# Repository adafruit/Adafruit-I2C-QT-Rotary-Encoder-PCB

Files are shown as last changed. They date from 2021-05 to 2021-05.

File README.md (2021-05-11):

## Adafruit I2C QT Rotary Encoder with NeoPixel - STEMMA QT / Qwiic PCB

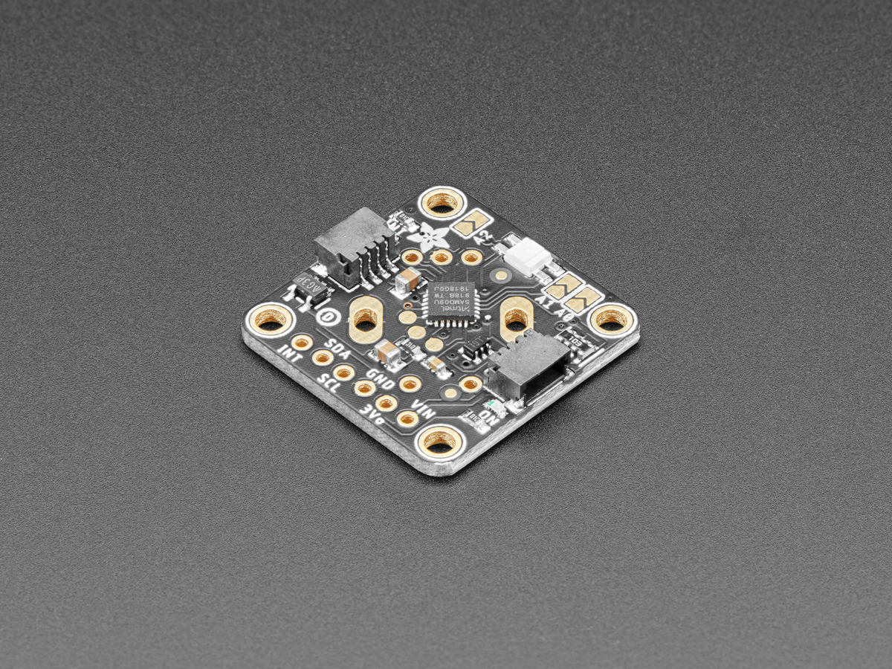
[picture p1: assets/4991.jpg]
<a href="http://www.adafruit.com/products/4991"><br/>
Click here to purchase one from the Adafruit shop</a>

PCB files for the Adafruit I2C QT Rotary Encoder with NeoPixel - STEMMA QT / Qwiic. 

Format is EagleCAD schematic and board layout
* https://www.adafruit.com/product/4991

### Description

Rotary encoders are soooo much fun! Twist em this way, then twist them that way. Unlike potentiometers, they go all the way around, and often have little detents for tactile feedback. But, if you've ever tried to add encoders to your project you know that they're a real challenge to use: timers, interrupts, debouncing...

This Stemma QT breakout makes all that frustration go away - solder in any 'standard' PEC11-pinout rotary encoder with or without a push-switch. The onboard microcontroller is programmed with our seesaw firmware and will track all pulses and pins for you and then save the incremental value for querying at any time over I2C. Plug it in with a Stemma QT cable for instant rotary goodness, with any kind of microcontroller from an Arduino UNO up to a Raspberry Pi.

You can use our Arduino library to control and read data with any compatible microcontroller. We also have CircuitPython/Python code for use with computers or single-board Linux boards.

It's also easy to add this breakout to a breadboard - with six 0.1"-spaced breakout pads. Power with 3 to 5V DC and then use 3 or 5V logic I2C data. The INT pin can be configured to pulse low whenever rotation or push-buttoning is detected so you do not have to spam-read the I2C port to detect motion.

There's a NeoPixel onboard, that can display any color you like. It's also controlled over I2C for additional visual feedback or keep it off if you like. On the back there's a green power LED as well as a red INT LED that, if the interrupt is configured, will blink when the interrupt fires.

Using the three onboard address jumpers, you can connect up to 8 of these rotary encoders on a single I2C port. The first one will be at address 0x36, the last one at 0x3D when all three jumpers are soldered closed.

To keep the board nice and compact, only 1" x 1" we made the footprint for the rotary encoder at a 45-degree angle. Since it rotates around freely there's no need for it to be at a 90-degree angle to the PCB. Each order comes with one assembled and tested PCB breakout and a small piece of header.

To get you going fast, we spun up a custom made PCB with the seesaw chip and all supporting circuitry, in the STEMMA QT form factor, making them easy to interface with. The STEMMA QT connectors on either side are compatible with the SparkFun Qwiic I2C connectors. This allows you to make solderless connections between your development board and the rotary encoder or to chain them with a wide range of other sensors and accessories using a compatible cable. QT Cable is not included, but we have a variety in the shop.

This breakout does not come with an encoder soldered on, so you can pick whatever encoder you like. We sell a common 24-detent-with-switch encoder here and it works wonderfully. You can also use encoders without detents or with a different number of detents per rotation, of course! You'll need to solder the encoder and optional header onto the PCB to use with a solderless breadboard. but it's fairly easy and takes only a few minutes even for a beginner.

### License

Adafruit invests time and resources providing this open source design, please support Adafruit and open-source hardware by purchasing products from [Adafruit](https://www.adafruit.com)!

Designed by Limor Fried/Ladyada for Adafruit Industries.

Creative Commons Attribution/Share-Alike, all text above must be included in any redistribution. 
See license.txt for additional details.

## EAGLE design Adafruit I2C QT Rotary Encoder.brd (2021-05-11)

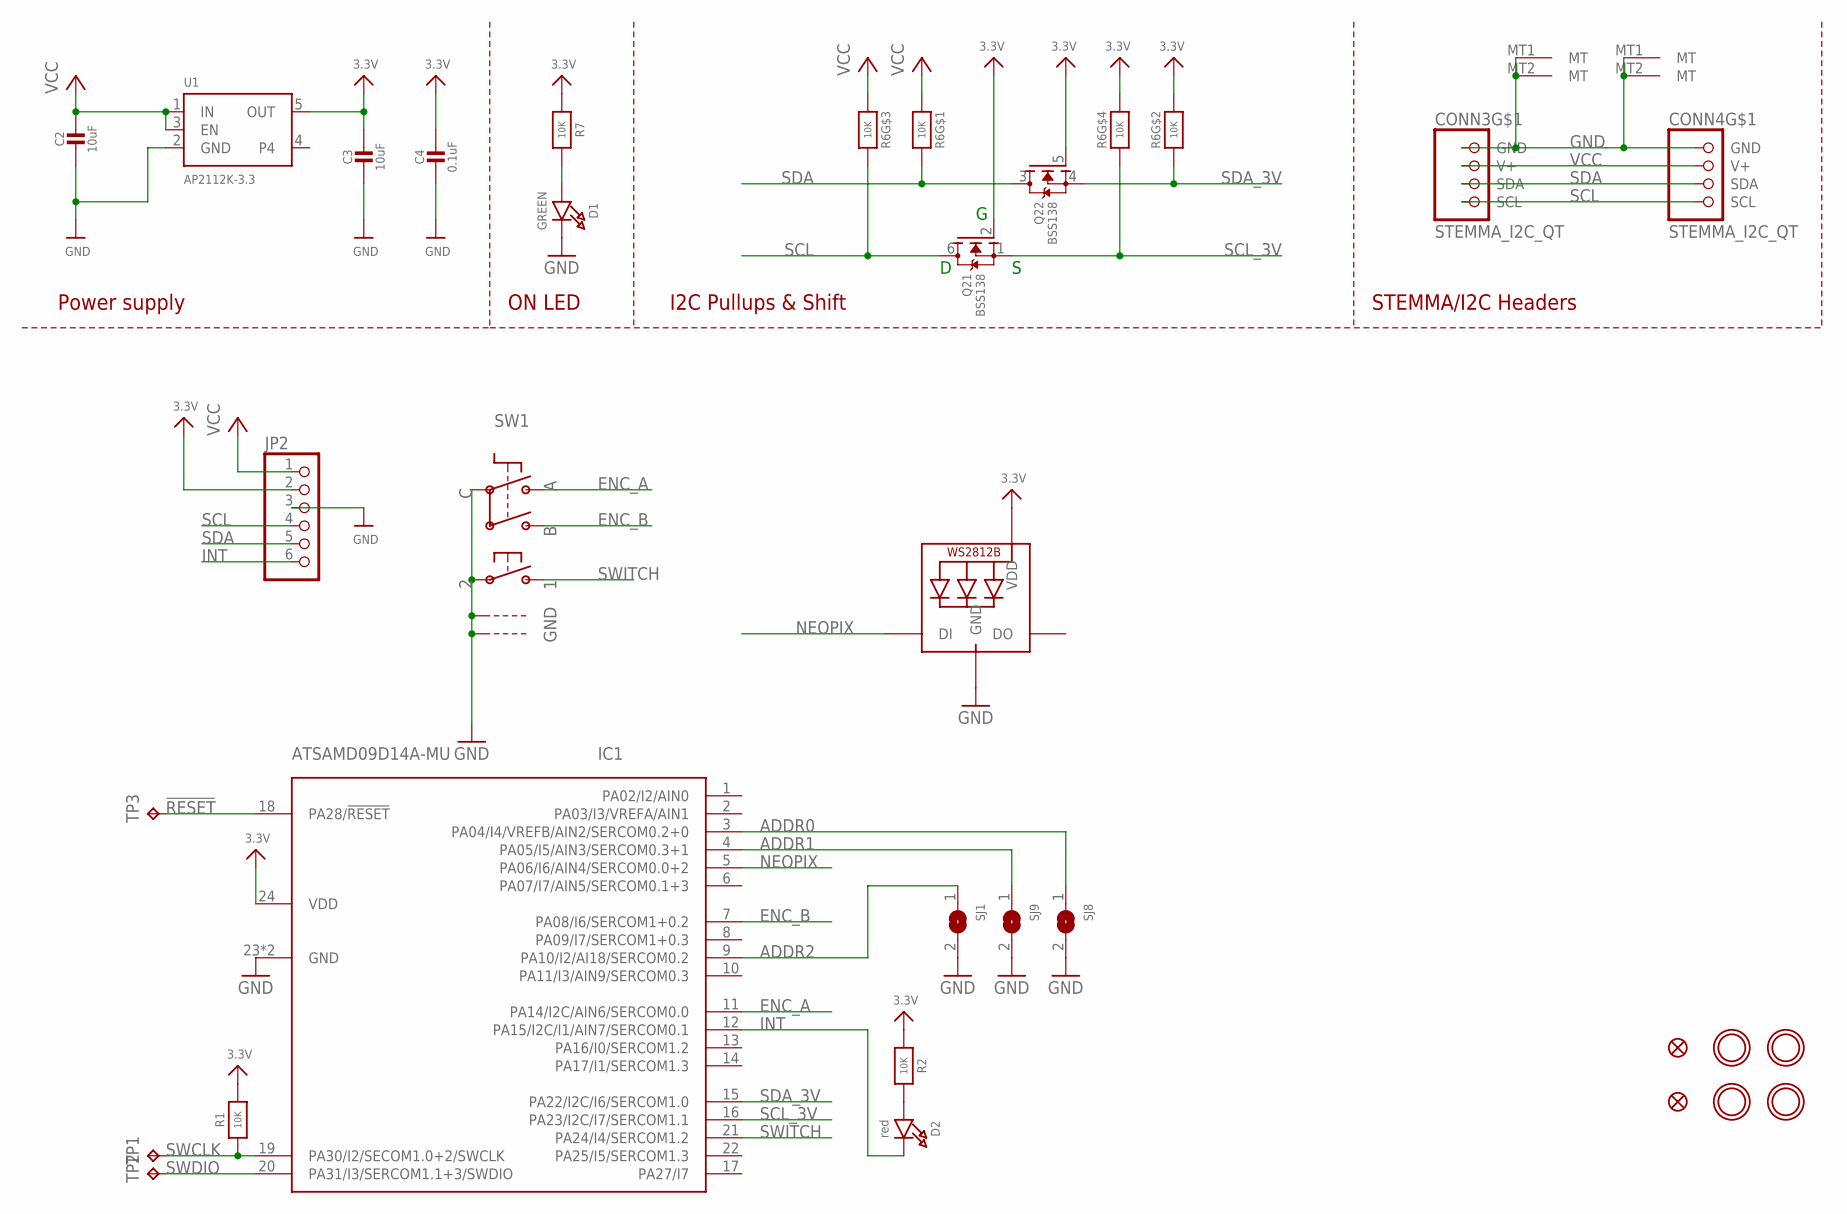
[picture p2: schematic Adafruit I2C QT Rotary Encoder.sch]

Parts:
C2, C3: 10uF; 0805-NO
C4: 0.1uF; 0603-NO
CONN3, CONN4: STEMMA_I2C_QT; JST_SH4
D1: GREEN; CHIPLED_0603_NOOUTLINE
D2: red; CHIPLED_0603_NOOUTLINE
FID3, FID4: FIDUCIAL_1MM
IC1: ATSAMD09D14A-MU; QFN24_4MM
JP2: HEADER-1X670MIL; 1X06_ROUND_70
LED1: WS2812B_SK6812E; NEO3535_REVERSE
Q2: BSS138; SOT363
R1, R2, R7: 10K; 0603-NO
R6: 10K; RESPACK_4X0603
SJ1, SJ8, SJ9: SOLDERJUMPER; SOLDERJUMPER_ARROW_NOPASTE
SW1: ENCODER_PLUS_SWITCH_BOURNS_PEC11; PEC11+SWITCH
TP1, TP2, TP3: TPTP15R; TP15R
U1: AP2112K-3.3; SOT23-5
U$25, U$27, U$29, U$30: MOUNTINGHOLE2.5; MOUNTINGHOLE_2.5_PLATED

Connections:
3.3V: C3.1, C4.1, IC1.24 (VDD), JP2.2, LED1.1-VDD (VDD), Q2.2 (G), Q2.5 (G), R1.2, R2.1, R6.2 (1), R6.4 (1), R7.1, U1.5 (OUT)
!RESET: IC1.18 (PA28/!RESET), TP3.TP
ADDR0: IC1.3 (PA04/I4/VREFB/AIN2/SERCOM0.2+0), SJ8.1
ADDR1: IC1.4 (PA05/I5/AIN3/SERCOM0.3+1), SJ9.1
ADDR2: IC1.9 (PA10/I2/AI18/SERCOM0.2), SJ1.1
ENC_A: IC1.11 (PA14/I2C/AIN6/SERCOM0.0), SW1.P$A
ENC_B: IC1.7 (PA08/I6/SERCOM1+0.2), SW1.P$B
GND: C2.2, C3.2, C4.2, CONN3.1 (GND), CONN3.MT1 (MT), CONN3.MT2 (MT), CONN4.1 (GND), CONN4.MT1 (MT), CONN4.MT2 (MT), D1.C, IC1.23 (GND), IC1.THERM (GND), JP2.3, LED1.3-GND (GND), SJ1.2, SJ8.2, SJ9.2, SW1.P$2, SW1.P$C, SW1.P$GND1, SW1.P$GND2, U1.2 (GND)
INT: D2.C, IC1.12 (PA15/I2C/I1/AIN7/SERCOM0.1), JP2.6
unnamed: D1.A, R7.2
unnamed: D2.A, R2.2
NEOPIX: IC1.5 (PA06/I6/AIN4/SERCOM0.0+2), LED1.4-DIN (DI)
SCL: CONN3.4 (SCL), CONN4.4 (SCL), JP2.4, Q2.6 (D), R6.6 (2)
SCL_3V: IC1.16 (PA23/I2C/I7/SERCOM1.1), Q2.1 (S), R6.5 (2)
SDA: CONN3.3 (SDA), CONN4.3 (SDA), JP2.5, Q2.3 (D), R6.8 (2)
SDA_3V: IC1.15 (PA22/I2C/I6/SERCOM1.0), Q2.4 (S), R6.7 (2)
SWCLK: IC1.19 (PA30/I2/SECOM1.0+2/SWCLK), R1.1, TP1.TP
SWDIO: IC1.20 (PA31/I3/SERCOM1.1+3/SWDIO), TP2.TP
SWITCH: IC1.21 (PA24/I4/SERCOM1.2), SW1.P$1
VCC: C2.1, CONN3.2 (V+), CONN4.2 (V+), JP2.1, R6.1, R6.3 (1), U1.1 (IN), U1.3 (EN)

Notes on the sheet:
I2C Pullups & Shift
STEMMA/I2C Headers
ON LED
Power supply

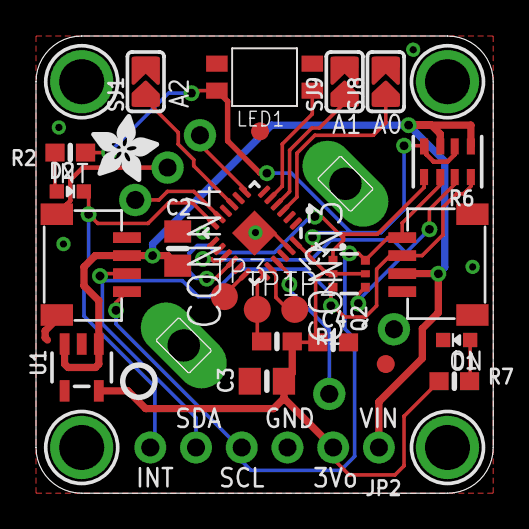
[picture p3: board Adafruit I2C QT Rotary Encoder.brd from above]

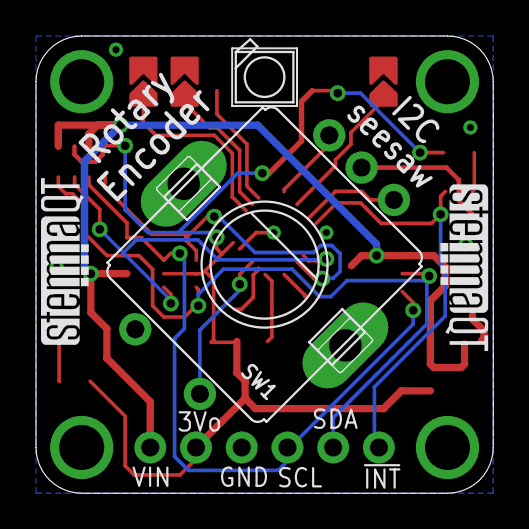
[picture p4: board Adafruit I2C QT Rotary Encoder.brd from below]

Board: 2 copper layers, 25.4 x 25.4 mm, 33 parts (4 on the bottom side), 20 nets.

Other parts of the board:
U$32: ADAFRUIT_3.5MM
U$33: PCBFEAT-REV-040
U$34, U$35: STEMMAQT

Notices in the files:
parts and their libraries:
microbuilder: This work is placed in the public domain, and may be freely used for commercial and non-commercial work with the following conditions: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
